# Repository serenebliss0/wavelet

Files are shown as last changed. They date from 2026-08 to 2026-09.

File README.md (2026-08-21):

<p align="center">
  
</p>

<p align="center">
  <b>A modular, open-source smart speaker platform built around the ESP32 ecosystem.</b>
</p>

<p align="center">
  
  
  
  
</p>

---

## Overview

Wavelet is a family of ESP32-based smart speakers built from a single shared codebase.

Each model targets a different use case, from a compact BLE-enabled desktop speaker to a future high-power smart speaker, while sharing the same firmware architecture through PlatformIO environments and compile-time feature flags.

The project is currently undergoing a major rewrite focused on modular firmware, modern embedded UI with LVGL and EEZ Studio, BLE onboarding, and a Flutter companion application.

---

## The Wavelet Family

| Model | Target | Current Status |
| --- | --- | --- |
| **Wavelet Mini** | ESP32-S3 | Active development |
| **Wavelet Regular** | ESP32-WROOM-32 | Being migrated to the new architecture |
| **Wavelet Max** | ESP32-S3 | Planned |

### Wavelet Mini

The Mini is the current focus of development and serves as the foundation for the rest of the Wavelet ecosystem.

It features:

- ESP32-S3
- LVGL + EEZ Studio interface
- QR-code BLE onboarding
- Wi-Fi provisioning
- Spotify API integration
- Battery monitoring
- RTC support
- Touchscreen interface

Unlike previous versions, the Mini no longer supports Bluetooth Classic audio. Instead, it focuses on becoming a connected smart speaker controlled through the companion app.

---

### Wavelet Regular

The Regular is the original portable stereo speaker.

The firmware is currently being migrated to the new modular architecture after much of the original implementation was replaced during Mini development.

Planned features include:

- Stereo audio
- Physical controls
- Battery operation
- Companion app support

---

### Wavelet Max

The Max is the planned flagship model.

It is intended to become a wall-powered smart speaker with significantly more processing power and expanded connectivity.

Development has not yet started as the required hardware is still being acquired.

---

## Project Status

| Feature | Mini | Regular | Max |
| :-- | :--: | :--: | :--: |
| BLE Onboarding | ✓ | Planned | Planned |
| LVGL + EEZ Studio | ✓ | N/A | N/A |
| Companion App Pairing | ✓ | Planned | Planned |
| Wi-Fi Provisioning | ✓ | N/A | Planned |
| Physical Buttons | In Progress | In Progress | Planned |
| Battery Monitoring | In Progress | Untested | N/A |
| Spotify API | In Progress | N/A | Planned |
| Bluetooth Audio | N/A | Broken (rewrite in progress) | N/A |
| OTA Updates | Planned | Planned | Planned |
| Clock Faces | Planned | N/A | N/A |

---

## Gallery

### Wavelet Mini UI
<p align="center">
  boot screen
  QR Setup page
  Onboarding Tutorial: Swipe down

</p>

---

## Repository Structure

```text
esp32-smart-speaker/
├── assets/
├── data/
├── esp32-smart-speaker-schema/
├── include/
├── lib/
├── src/
│   ├── audio/
│   ├── ble/
│   ├── core/
│   ├── input/
│   ├── mini/
│   ├── screens/
│   ├── spotify_controller/
│   ├── storage/
│   ├── web/
│   ├── wifi/
│   └── main.cpp
├── spk-sounds/
├── test/
├── wavelet_app/          Flutter companion app (Git submodule)
├── webpage_iterations/
└── platformio.ini
```

---

## Getting Started

Clone the repository together with the companion app submodule.

```bash
git clone --recursive https://github.com/serenebliss0/wavelet.git
```

If you've already cloned the repository:

```bash
git submodule update --init --recursive
```

Install PlatformIO if needed.

```bash
pip install platformio
```

Build the desired firmware:

```bash
pio run -e mini
```

or

```bash
pio run -e regular
```

or

```bash
pio run -e max
```

Upload to your board:

```bash
pio run -t upload -e mini
```

---

## Roadmap

### Wavelet Mini

- [x] QR BLE onboarding
- [x] LVGL integration
- [x] EEZ Studio integration
- [x] Companion app pairing
- [x] Wi-Fi provisioning
- [ ] Clock faces
- [ ] Spotify interface
- [ ] Battery management
- [ ] Settings pages

### Wavelet Regular

- [ ] Restore Bluetooth audio
- [ ] Migrate to new architecture
- [ ] Companion app support

### Wavelet Max

- [ ] Hardware prototype
- [ ] Firmware foundation
- [ ] Network services
- [ ] OTA updates
- [ ] Smart home integration

---

## Companion Application

Wavelet includes a Flutter companion application used for:

- Onboarding
- BLE pairing
- Wi-Fi setup
- Device management
- Future firmware updates

The app lives in its own repository and is included here as a Git submodule.

**Repository:** https://github.com/serenebliss0/wavelet-app

---

## Built With

- C++
- Arduino Framework
- PlatformIO
- LVGL 8.4
- EEZ Studio
- NimBLE
- ArduinoJson
- Flutter
- Dart

---

## Contributing

Contributions, suggestions and bug reports are always welcome.

If you have ideas or improvements, feel free to open an issue or submit a pull request.

---

## License

MIT License

---

Made with ❤️ by **Semire Ajayi**

## Figma Designs

---

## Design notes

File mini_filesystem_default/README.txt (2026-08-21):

========================================
           WAVELET MINI
========================================

Welcome!

If you're reading this, then congratulations!
You're one of the few people curious enough
to open a README file on an embedded device.

This SD card stores Wavelet's settings,
cache, logs and media.

Please avoid modifying files inside the
/system folder unless you know what you're doing.

Even if you know what you're doing,
Wavelet reserves the right to panic anyway : )

Need help?
Create an issue on the GitHub Repository!
https://github.com/serenebliss0/esp32-smart-speaker

----------------------------------------

Fun fact:
The wavelet mini was inspired by a Mac Studio

----------------------------------------

Have an amazing day.

With love
~ Semire (2026)

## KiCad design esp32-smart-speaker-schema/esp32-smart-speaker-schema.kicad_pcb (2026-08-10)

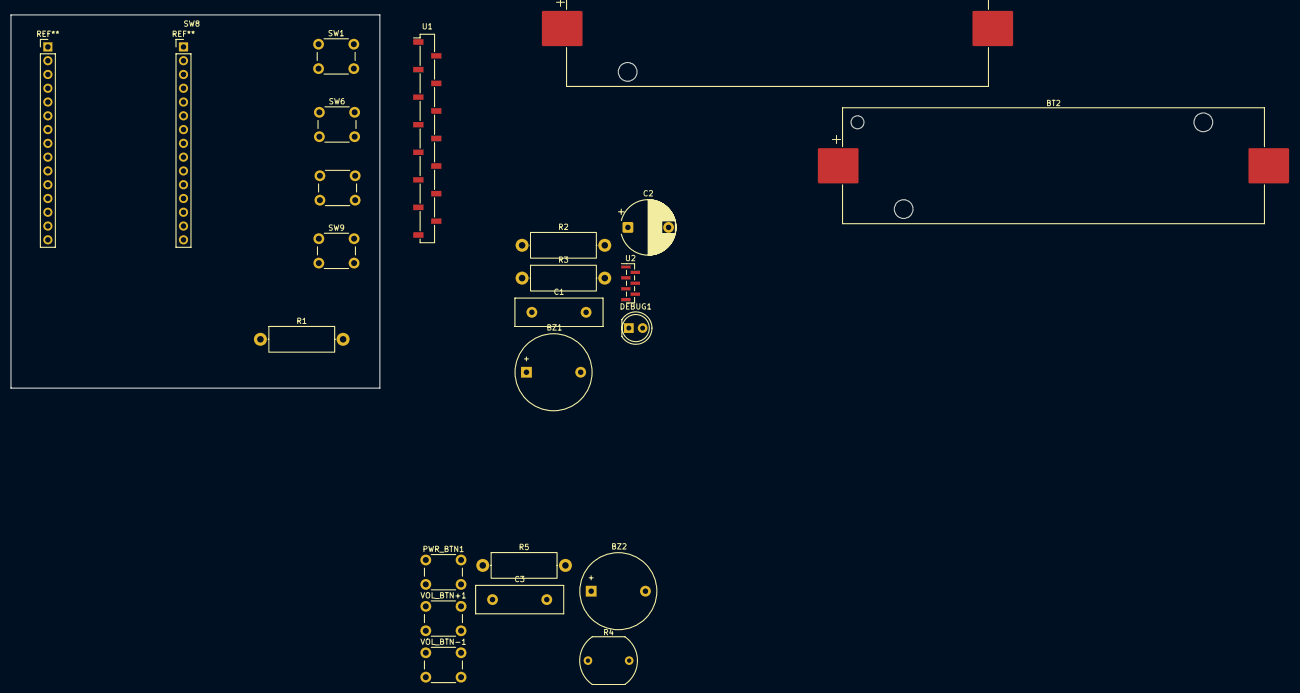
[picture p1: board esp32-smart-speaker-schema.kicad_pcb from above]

Board: 2 copper layers, 68.0 x 68.8 mm, 22 parts (0 on the bottom side), 8 nets, no tracks yet.

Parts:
BT1, BT2: Battery; BatteryHolder_Keystone_1042_1x18650
BZ1, BZ2: Buzzer; Buzzer_D14mm_H7mm_P10mm
C1: C; C_Disc_D16.0mm_W5.0mm_P10.00mm
C2: C_Polarized; CP_Radial_D10.0mm_P7.50mm
C3: 100n; C_Disc_D16.0mm_W5.0mm_P10.00mm
DEBUG1: LED; LED_D5.0mm
PWR_BTN1: SW_Push; SW_PUSH_6mm
R1: 220; R_Axial_DIN0414_L11.9mm_D4.5mm_P15.24mm_Horizontal
R2, R3, R5: 10k; R_Axial_DIN0414_L11.9mm_D4.5mm_P15.24mm_Horizontal
R4: LDR03; R_LDR_10x8.5mm_P7.6mm_Vertical
SW1: PAUS_BTN; SW_PUSH_6mm
SW6: PWR_BTN; SW_PUSH_6mm
SW8: PREV_BTN; SW_PUSH_6mm
SW9: NXT_BTN; SW_PUSH_6mm
U1: PinSocket_1x15_P2.54mm_Vertical_SMD_Pin1Left
U2: MAX98357A; PinHeader_1x07_P1.00mm_Vertical_SMD_Pin1Left
VOL_BTN+1: SW_Push; SW_PUSH_6mm
VOL_BTN-1: SW_Push; SW_PUSH_6mm

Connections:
+5V: C1.1, C2.1, DEBUG1.2 (A), U2.4 (~SD_MODE), U2.7 (VDD)
/BAT_LEVEL: R2.2, R3.2, U1.11 (GPIO35)
/BUZZER: BZ1.1 (+), U1.6 (GPIO27)
/PAUS_BTN: SW1.1, U1.3 (GPIO13)
/Wavelet Mini/3.3V: C3.1, R4.2
/Wavelet Mini/GPIO3: R4.1, R5.2
GND: BZ1.2 (-), BZ2.2 (-), C1.2, C2.2, C3.2, PWR_BTN1.2, R1.2, R2.1, R3.1, R5.1, SW1.2, SW6.2, SW8.2, SW9.2, U1.2 (GND), U2.2 (GAIN_SLOT), U2.3 (GND), VOL_BTN+1.2, VOL_BTN-1.2
unnamed: DEBUG1.1 (K), R1.1

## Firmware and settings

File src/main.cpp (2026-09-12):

/*
 * Project Name: Wavelet
 * Description: A family of ESP32-based smart speakers built from a single shared codebase.
 * Author: Semire Ajayi
 * Date: 12-MAR-2026
 * 
 * Hardware:
 * 
 * (Mini)
 * - 1x 2.8inch ESP32-S3 Display Module
 * - 2x 18650 Lithium Batteries
 * - 1x 4ohm, 8-Watt Speaker 
 * - 1x Passive Buzzer
 * - 1x Light Dependent Resistor (LDR)
 * - 3x Push Buttons
 * 
 * (Regular)
 * - 1x ESP32 DevKit V1
 * - 1x MAX98357A I2S Amplifier
 * - 1x 4ohm, 8-Watt Speaker 
 * - 1x Passive Buzzer
 * - 2x 18650 Lithium Batteries
 * - 1x TP4056 Charging Module
 * - 1x 5k-ohm Potentiometer
 * - 4x Push Buttons
 * 
 * Connections:
 * (See Config.h for wavelet regular, MiniConfig for wavelet mini)
 * 
 */

#include <Arduino.h>
#include <WiFi.h>
#include "driver/i2s.h"
#include <Preferences.h>

#ifdef WAVELET_MINI
#include "mini/mini-setup-assistant.h" //contains functionality for the wavelet mini
#endif

#if defined(WAVELET_REGULAR)
#include "input/Buttons.h"
#include "audio/AudioManager.h"
#include "ble/BLEManager.h"
#include "core/Speaker.h"
#include "BluetoothA2DPSink.h"
#include "storage/PreferencesManager.h"
#endif


#ifdef WAVELET_MAX
#include "web/WebServer.h"
#include "wifi/WiFiManager.h"
#endif

Preferences prefs;

//Regular is quite cooked rn
#ifdef WAVELET_REGULAR
#include "Config.h"
AudioManager audio(prefs);
BluetoothA2DPSink a2dp_sink;
#endif

// comment this line to disable debug
#define DEBUG

//uncomment this line to enable BatteryStats
#define BATTERIES_CONNECTED

#define MINI_FIRMWARE_VERSION "0.2.0"
#define REGULAR_FIRMWARE_VERSION "1.0.0"
#define MAX_FIRMWARE_VERSION "1.0.0"


void setup() {

    #ifdef DEBUG
    Serial.begin(115200);
    #endif

    ledcSetup(0, 2000, 8);

    // prefs.begin("app", false); // open once
    prefs.begin("wavelet", false);


    #if defined(WAVELET_REGULAR)
    pinMode(Config::BUZZER, OUTPUT);
    pinMode(Config::PWR_BUTTON, INPUT_PULLUP);
    pinMode(Config::MODE_BUTTON, INPUT_PULLUP);
    pinMode(Config::PREVIOUS_BUTTON, INPUT_PULLUP);
    pinMode(Config::NEXT_BUTTON, INPUT_PULLUP);
    pinMode(Config::PAUSE_BUTTON, INPUT_PULLUP);
    #endif

    #ifdef WAVELET_MINI
    initializeDisplay();
    startLED();
    initializePreferences();
    startOrCheckOnboarding();
    startFeatures();
    #endif

    #ifdef DEBUG
    // String mac_addr = WiFi.macAddress();
    Serial.println(WiFi.macAddress());
    #endif

    #ifdef WAVELET_REGULAR
    i2s_pin_config_t my_pins = {
        .bck_io_num = 26,
        .ws_io_num = 25,
        .data_out_num = 4, //DIN
        .data_in_num = I2S_PIN_NO_CHANGE
    };

    a2dp_sink.set_pin_config(my_pins);
    a2dp_sink.set_on_connection_state_changed(on_connected);
    a2dp_sink.set_auto_reconnect(false);
    #endif

    #ifdef WAVELET_MAX
    getSongMetadata(); //achieve song info for the web ui
    #endif

    #ifdef WAVELET_REGULAR //update required
    a2dp_sink.start("Wavelet");
    #endif

    #ifdef WAVELET_MAX
    a2dp_sink.start("Wavelet Max");
    #endif

  
    // audio.play_startup_sound();

    // int rememberedVolume = readRememberedVolume();
    // a2dp_sink.set_volume(rememberedVolume);
    // //i2s_set_clk(I2S_NUM_0, 44100, I2S_BITS_PER_SAMPLE_16BIT, I2S_CHANNEL_STEREO);
    // audio.buzz(1000,1000);

    #ifdef WAVELET_MAX
    connectWiFi();
    delay(5000);
    startWebServer();
    getSongMetadata();
    #endif
}

void loop() {

    //mini
    #ifdef WAVELET_MINI
    //LVGL events
    lv_timer_handler();
    ui_tick();

    //Neopixel LED handler
    ledUpdate();

    //WiFi
    processBleSetup();

    //Spotify
        // updateSpotify();
        handleSpotifyLoop();
    #endif

    #if defined(WAVELET_REGULAR)

    #ifdef DEBUG
    int battery_level = readBatteryLevel();
    Serial.println(battery_level);
    #endif

    update_battery();
    checkModeButton();
    handlePowerButton();
    handlePreviousButton();
    handleNextButton();
    #endif

}

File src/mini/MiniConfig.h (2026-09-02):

#pragma once

//Configuration file for the Wavelet Mini
//If you are looking for the regular's config:
// src/Config.h


//Contains pins, and other params
namespace MiniConfig {

    //Audio 
    constexpr int LED_PIN = 42;
    constexpr int BATTERY_PIN = 9;
    constexpr int BUZZER = 27;


    //Pwr and Mode
    constexpr int PWR_BUTTON = 23;
    constexpr int MODE_BUTTON = 21;
    
    constexpr const char* deviceName = "Wavelet";

}

//Display
//Pins
constexpr int TOUCH_FT6336_SCL = 15;
constexpr int TOUCH_FT6336_SDA = 16;
constexpr int TOUCH_FT6336_INT = 17;
constexpr int TOUCH_FT6336_RST = 18;
//Other param
constexpr int TOUCH_MAP_X1 = 0;
constexpr int TOUCH_MAP_X2 = 240;
constexpr int TOUCH_MAP_Y1 = 0;
constexpr int TOUCH_MAP_Y2 = 320;

//Battery
constexpr float ADC_REFERENCE = 3.3f;
constexpr int ADC_RESOLUTION = 4095;
constexpr float VOLTAGE_DIVIDER = 2.0f;

//SD Card
constexpr int SD_CLK = 38;
constexpr int SD_CMD = 40;
constexpr int SD_D0 = 39;
constexpr int SD_D1  = 41;
constexpr int SD_D2  = 48;
constexpr int SD_D3  = 47;

//Buttons
const int PLAY_BUTTON = 2; //play/pause
const int VOL_UP_BUTTON = 3;
const int VOL_DOWN_BUTTON  = 14;

//Audio
const int AUDIO_I2C_SDA = 16;   //(shared with touch + extended I2C)
const int AUDIO_I2C_SCL = 15;   //(shared with touch + extended I2C)
const int AUDIO_I2S_MCLK = 4;
const int AUDIO_I2S_BCK = 5;
const int AUDIO_I2S_DOUT = 8;
const int AUDIO_I2S_WS  = 7;
const int AUDIO_AMP_ENABLE  = 1;

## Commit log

2026-08-04 Started developing backend for wavelet mini
    [esp32-smart-speaker-schema.kicad_sch, wavelet_mini.kicad_sch]
2026-08-06 Finally started development for Wavelet Mini.
    What's new:
    - QR code onboarding
    - Touchscreen drivers
    - EEZ Studio UI integration
    - Firmware refactor for Mini
    - ESP32-S3 compatibility
    Regression:
    - Wavelet Regular is no longer feeling very regular.
    [wavelet_mini.kicad_sch]
2026-08-10 Updated UI to actually display the correct manual code instead of a placeholder
    [esp32-smart-speaker-schema.kicad_pcb, esp32-smart-speaker-schema.kicad_sch, wavelet_mini.kicad_sch]
2026-08-21 Revise README for Wavelet device features and UI
    Updated feature support details for Wavelet devices and removed outdated sections.
2026-08-21 Trying to fix bug regarding new partition scheme
    [mini.csv]
2026-08-22 Attempt to fix Spotify and SSL issues
    [BLEManager.cpp, Spotify.cpp, main.cpp]
2026-08-23 - Developed WiFiManager for managing WiFi connections with stored credentials. - Implemented album art caching functionality in the Spotify controller. - Completely fixed the Serial Monitor issue - F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
    [Spotify.cpp, WiFiManager.cpp, album_art.cpp]
2026-08-24 Major code refactoring for the Wavelet Mini codebase.
    - Deleted unused screens and the old screens/ directory
    - Updated Spotify.cpp to improve button handling by removing unused button states and adding logging for button initialization.
    - Simplified comments and organized code structure in Spotify.cpp for better readability.
    - Enhanced Spotify.h by removing redundant comments and clarifying function purposes.
    - Added logging functionality in more modules for better error tracking.
    - Moved pin definitions and some constants to MiniConfig.h
    [BLEManager.cpp, MiniConfig.h, Spotify.cpp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]
2026-08-25 Added audio manager module (currently broken)
    [Es8311Wire.cpp, mini-audio-manager.cpp]
2026-08-29 Changed pin mappings for audio functions
2026-08-31 Fixed config file for wavelet mini
    [MiniConfig.h, mini-audio-manager.cpp]
2026-09-02 Fixed audio pipeline
    - Boot chime now plays properly
    - Touch and audio coexistence fixed
    - Fixed pin numbers
    - Merged modularized code to audio-module
    [main.cpp, mini-audio-manager.cpp]
2026-09-12 Update UI assets and project configuration
    - Increased the size of the assets array in ui.h from 4372 to 4788 bytes to accommodate new resources.
    - Adjusted the height of a UI component from 69 to 68 pixels for better alignment.
    - Modified the width of another UI component from 329 to 335 pixels to improve layout.
    - Changed the screen transition action from "Onboarding2" to "DefaultClock" for a more relevant user experience.
    - Added a new source file ui_font_font_icons.c to include additional font icons for the UI.
    Issues:
    - Broke screen order again
    [BLEManager.cpp]
2026-09-12 Fixed scope issues with Preferences
    - Removed local versions of prefs in BLEManager, WiFiManager, qr_setup, and mini-setup-assistant
    -Fixed a bug in the companion app that caused the wavelet to infinitely wait for "SETUP_DONE"
    -Updated UI elements
    - Fixed logic for setup process
    -Started work on the main user interface of the wavelet mini
    - Removed some Logger functionality in BLEManager as it was causing crashes
    - Partially fixed the issue with screen loading order caused by a duplicated lvgl block in EEZ
    - Migrated some screen transitions to the main codebase from EEZ
    [BLEManager.cpp, WiFiManager.cpp, main.cpp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]
2026-09-12 resolve Spotify API response parsing issues
    -Updated Certificates in SpotifyESP32.h
    - Fix HTTP header parser assuming Content-Length is last
    - Correct response body parsing for Spotify API requests
    - Restore proper JSON response handling
    - Verify currently playing track and album art retrieval
2026-10-24 feat(mini): add BLE controls, gesture navigation, and live volume - Add BLE speaker controls for playback, volume, themes, repeat, shuffle, time sync, status, and Spotify credentials - Add swipe navi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
2026-10-25 Add mini UI controls for Spotify and system settings
    - Implemented mini_ui_controls.cpp and mini_ui_controls.h to manage UI interactions for Spotify features, WiFi, Bluetooth, Do Not Disturb, and brightness control.
    - Added event handlers for button clicks and slider changes to update preferences and control device features.
    - Introduced functions to initialize and update UI controls based on user preferences and system state.
    - Added large font and default album cover image files for UI display.
2026-10-25 feat(mini): About pages, hidden SecretPage, and named-widget cleanup
    About
    - Add About Wavelet pages with QR code and a "Made with ♥ from
    Semire Designs" credit
    - Swipe-right returns to Settings via a native gesture action that
    checks swipe direction
    - Downsize the heart bitmap to screen-appropriate dimensions (the
    original 2399x2141 rendered as scanlines and would have eaten flash)
    Easter egg
    - Add SecretPage: fake Amiga-style Guru Meditation with a blinking
    red border, driven entirely by an EEZ flow loop (SetVariable + Delay)
    - Trigger by tapping the logo 7 times (Counter -> Change Screen)
    - Intentional dead end: no exits, no persisted state, power cycle
    always recovers
    Fixes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
